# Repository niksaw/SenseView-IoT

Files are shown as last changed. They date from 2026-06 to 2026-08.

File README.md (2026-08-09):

# SenseView – Modular IoT Environmental Monitoring Platform

> **An end-to-end IoT platform engineered from concept to deployment, integrating custom hardware, embedded firmware, and a scalable edge-to-cloud data pipeline.**

<p align="center">
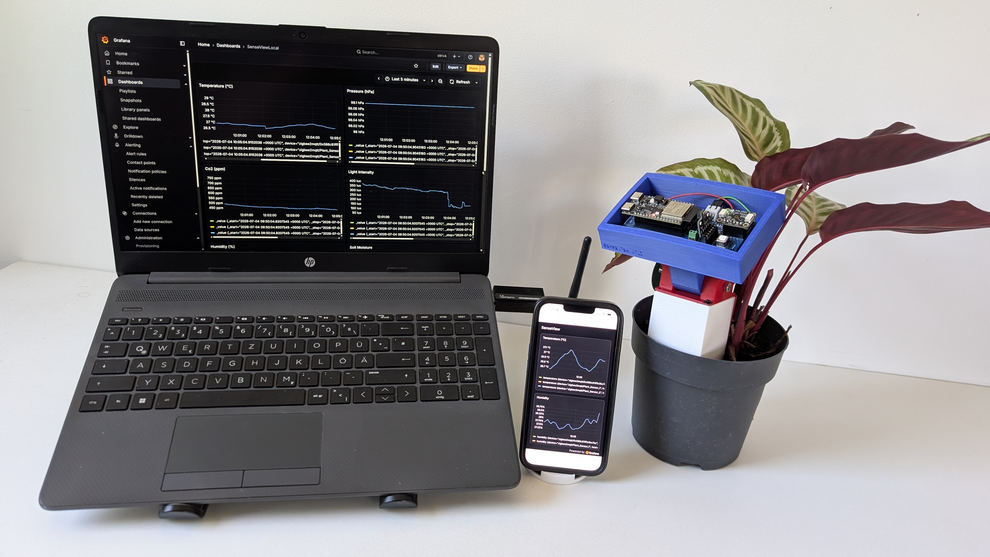
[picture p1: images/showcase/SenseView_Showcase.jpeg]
  
</p>
<p align="center">
  
  
  
  
</p>

## Overview

SenseView is a battery-powered IoT environmental monitoring platform developed to demonstrate the complete lifecycle of an embedded IoT system—from hardware design and firmware development to data acquisition, visualization, and cloud integration.

Originally developed as part of a Master's thesis in Electrical and Microsystems Engineering, the project was driven by research objectives emphasizing measurement quality, reliability, modularity, and low-power operation rather than minimizing hardware cost. Consequently, hardware and sensor selection were based on engineering requirements rather than cost optimization.

The platform combines a custom-designed ESP32-C6 sensor node, modular embedded firmware, and a complete MQTT-based backend capable of simultaneously storing data in both local and cloud time-series databases. Although the current implementation uses Zigbee communication, the architecture was intentionally designed to support future migration to Wi-Fi or Thread/Matter with minimal changes.

---

# System Architecture

<p align="center">
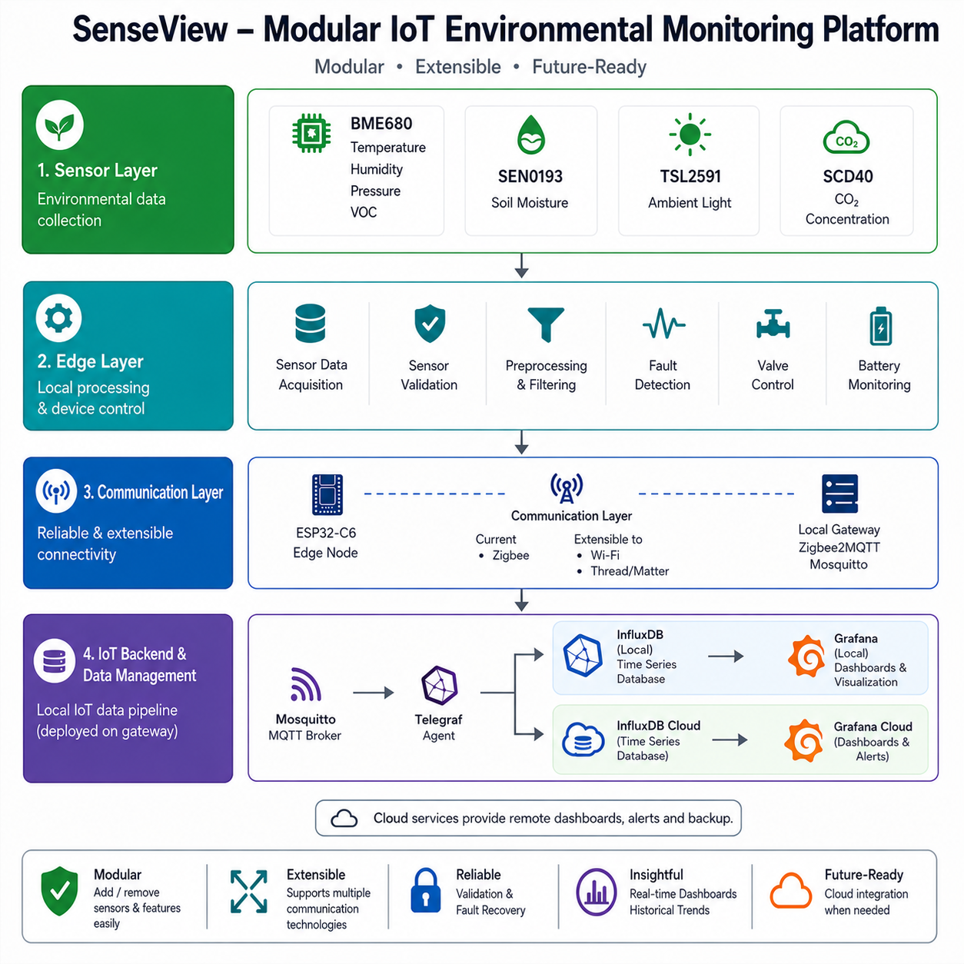
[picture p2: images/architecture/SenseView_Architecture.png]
  
</p>

---

# Engineering Highlights

- Designed and manufactured a custom ESP32-C6 PCB using KiCad.
- Developed embedded firmware for environmental sensing, sensor validation, preprocessing, fault detection, battery monitoring, and automated irrigation control.
- Built a complete MQTT-based IoT backend using Mosquitto, Telegraf, InfluxDB, and Grafana.
- Implemented simultaneous local and cloud data storage using Telegraf dual-output configuration.
- Designed the communication layer to remain extensible to Zigbee, Wi-Fi, and Thread/Matter.
- Designed a custom deployment enclosure using SolidWorks.
- Integrated environmental sensing, data visualization, and irrigation control into a single modular IoT platform.

---

# Technology Stack

| Category | Technology |
|---|---|
| Microcontroller | ESP32-C6 |
| Sensors | SCD40, BME680, TSL2591, SEN0193 |
| Communication | Zigbee (Extensible to Wi-Fi & Thread/Matter) |
| Firmware | Arduino Framework (C++) |
| MQTT Broker | Mosquitto |
| Data Collection | Telegraf |
| Database | InfluxDB + InfluxDB Cloud |
| Dashboard | Grafana + Grafana Cloud |
| PCB Design | KiCad |
| Mechanical Design | SolidWorks |

---

# Gallery

## Complete Device
Battery-powered prototype assembled inside the custom enclosure prior to deployment.
<p align="center">
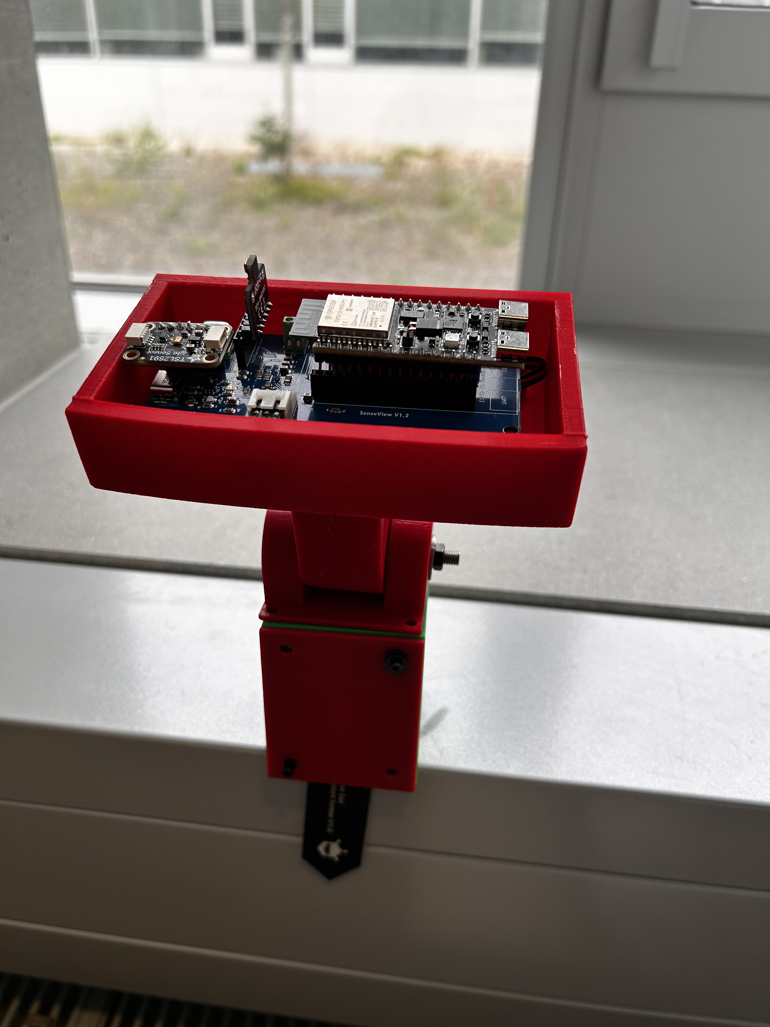
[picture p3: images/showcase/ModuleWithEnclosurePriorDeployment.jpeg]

</p>

## Custom PCB
PCB integrating the ESP32-C6, environmental sensors, battery management, and expansion headers.
<p align="center">
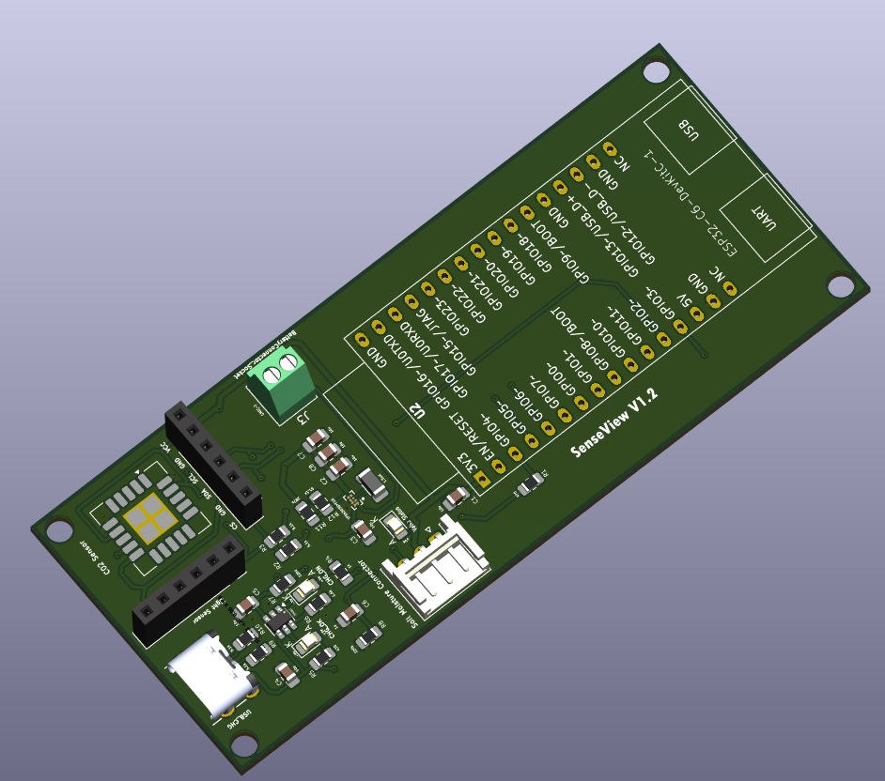
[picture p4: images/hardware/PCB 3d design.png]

</p>

## Grafana Dashboard
Real-time visualization of environmental data collected from the deployed sensor node
<p align="center">
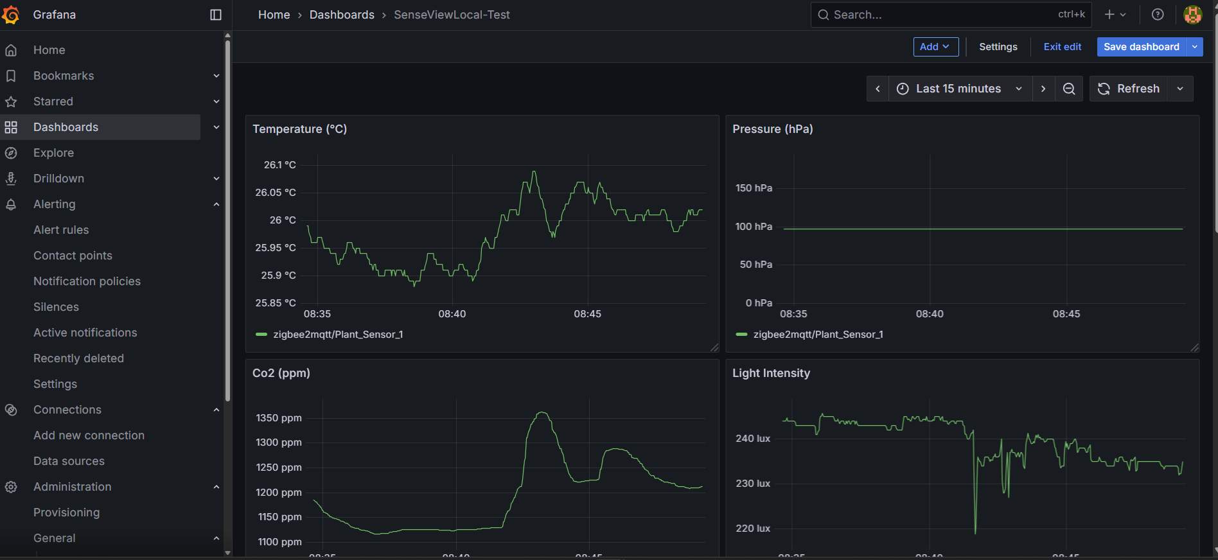
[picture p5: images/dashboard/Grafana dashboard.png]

</p>

## Deployment
Prototype deployed for indoor environmental monitoring
<p align="center">
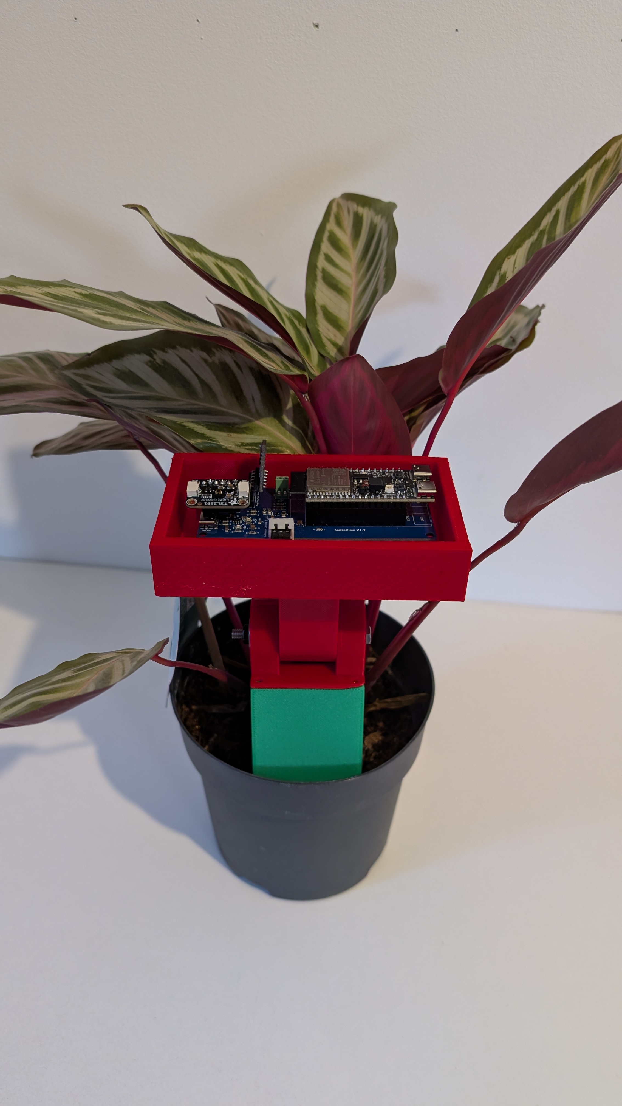
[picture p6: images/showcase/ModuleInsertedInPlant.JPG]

</p>

---

# Hardware

## Microcontroller

- ESP32-C6 Development Board

## Sensors

| Sensor | Purpose |
|---|---|
| Sensirion SCD40 | CO₂ Concentration |
| Bosch BME680 | Temperature, Humidity, Pressure, VOC |
| Adafruit TSL2591 | Ambient Light |
| DFRobot SEN0193 | Soil Moisture |

## Additional Hardware

- Custom PCB
- Li-Po Battery
- Solenoid Valve
- Custom 3D Printed Enclosure

---

# Software Architecture

## Embedded Firmware

- Sensor acquisition
- Sensor validation
- Data preprocessing
- Battery monitoring
- Irrigation control
- Fault detection

## Communication

- Zigbee
- Zigbee2MQTT

## Backend

- Mosquitto MQTT Broker
- Telegraf
- Local InfluxDB
- InfluxDB Cloud
- Local Grafana
- Grafana Cloud

---

# Repository Structure

```text
firmware/
    ESP32-C6 firmware

hardware/
    bom/
    gerbers/
    kicad/

enclosure/
    SolidWorks enclosure

images/
    architecture/
    dashboard/
    hardware/
    showcase/
```

---
# Engineering Decisions

| Decision | Reason |
|---|---|
| ESP32-C6 | Supports Zigbee, Wi-Fi and native Thread, enabling a modular communication architecture. |
| Zigbee | Low-power communication suitable for battery-operated IoT devices and readily available laboratory infrastructure. |
| BME680 | Higher measurement capability including VOC sensing compared to BME280. |
| Custom PCB | Improved robustness, compactness and deployment reliability compared to breadboard prototypes. |
| Telegraf | Flexible preprocessing and simultaneous transmission to both local and cloud InfluxDB instances. |

---

# Engineering Challenges

Some of the most significant engineering challenges encountered during this project included:

- Designing a reliable battery-powered power supply and custom PCB.
- Developing a complete IoT backend from MQTT through cloud visualization.
- Developing custom Zigbee2MQTT integration for seamless communication with the local IoT infrastructure.
- Designing a modular architecture capable of supporting future communication technologies with minimal hardware changes.

---

# Future Improvements

- Wi-Fi communication backend
- Native Thread / Matter implementation
- OTA firmware updates
- Further power optimization
- Configuration interface
- Mobile application

---

# Project Background

This project was developed as part of a Master's thesis in Electrical and Microsystems Engineering at OTH Regensburg.

Rather than focusing on building a single-purpose plant monitoring device, the objective was to engineer a reusable IoT platform capable of supporting environmental sensing applications while remaining modular, scalable and suitable for future communication technologies.

---

# Acknowledgements

I would like to thank my thesis supervisor and OTH Regensburg for providing the opportunity and research environment for this project.

---

# License

This project is licensed under the MIT License.

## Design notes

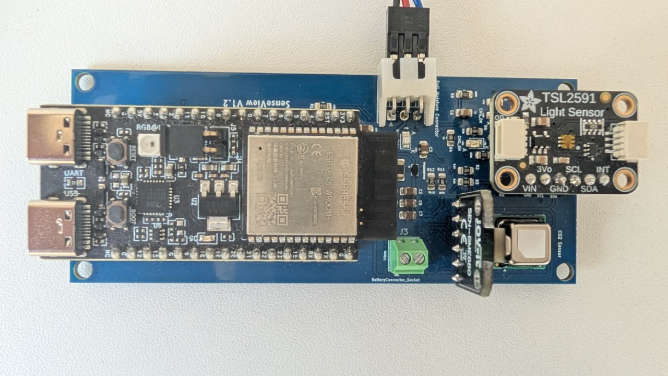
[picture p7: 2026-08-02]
images/hardware/TopView.png

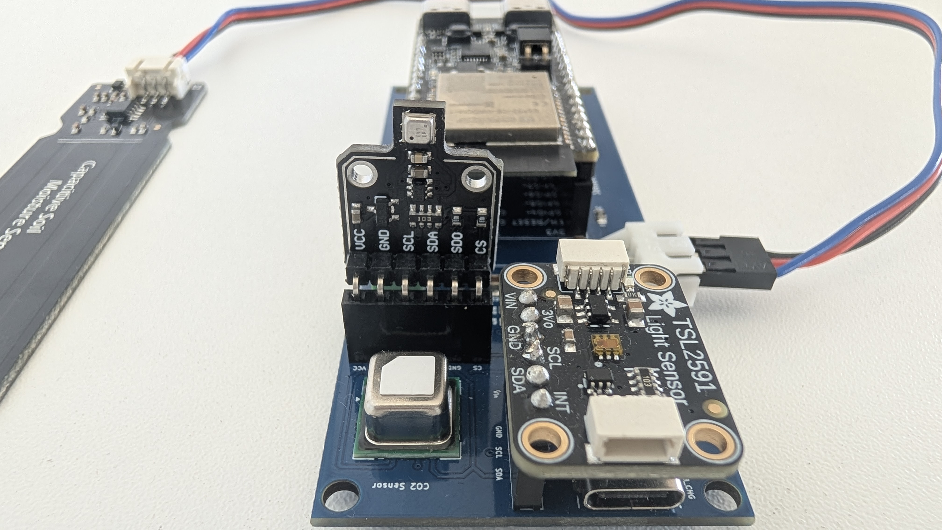
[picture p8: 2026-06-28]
images/hardware/SideView_3.jpeg

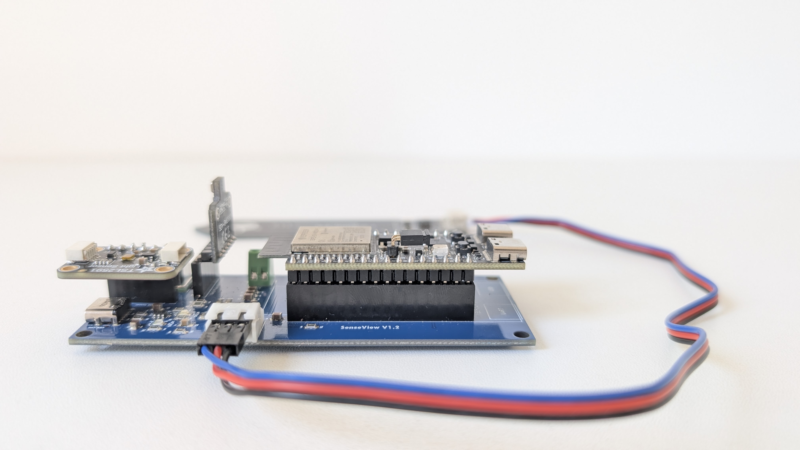
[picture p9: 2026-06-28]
images/hardware/SideView_1.jpeg

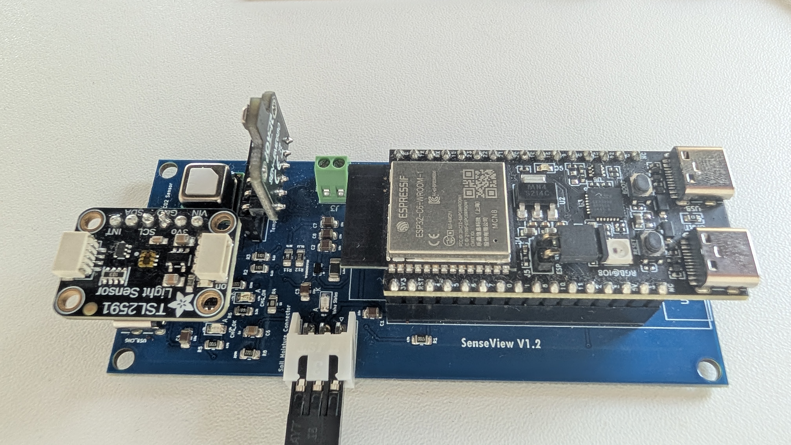
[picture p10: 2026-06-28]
images/hardware/SideView_2.jpeg

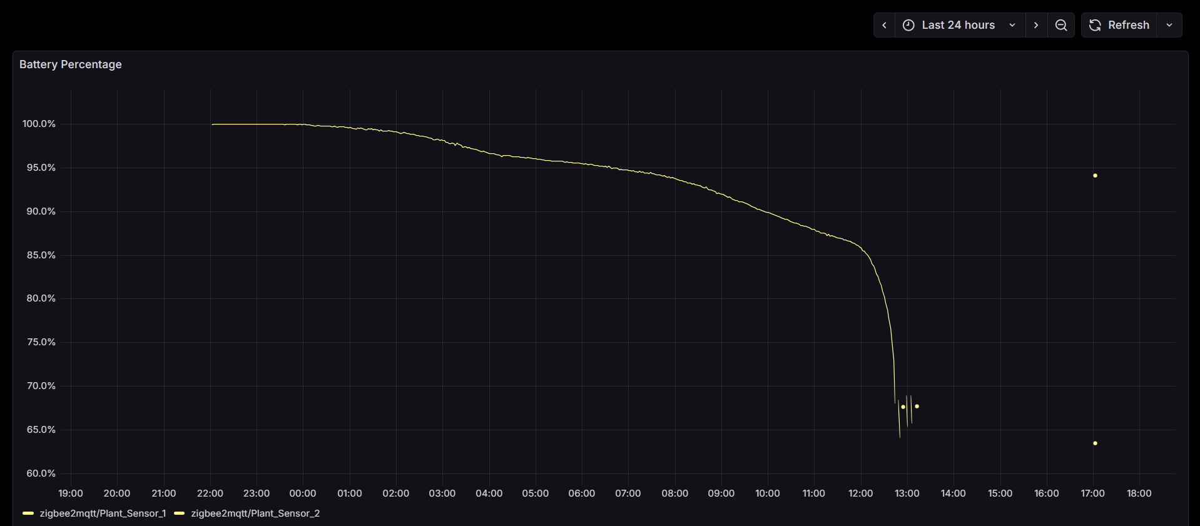
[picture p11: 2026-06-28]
images/dashboard/Battery SC.png

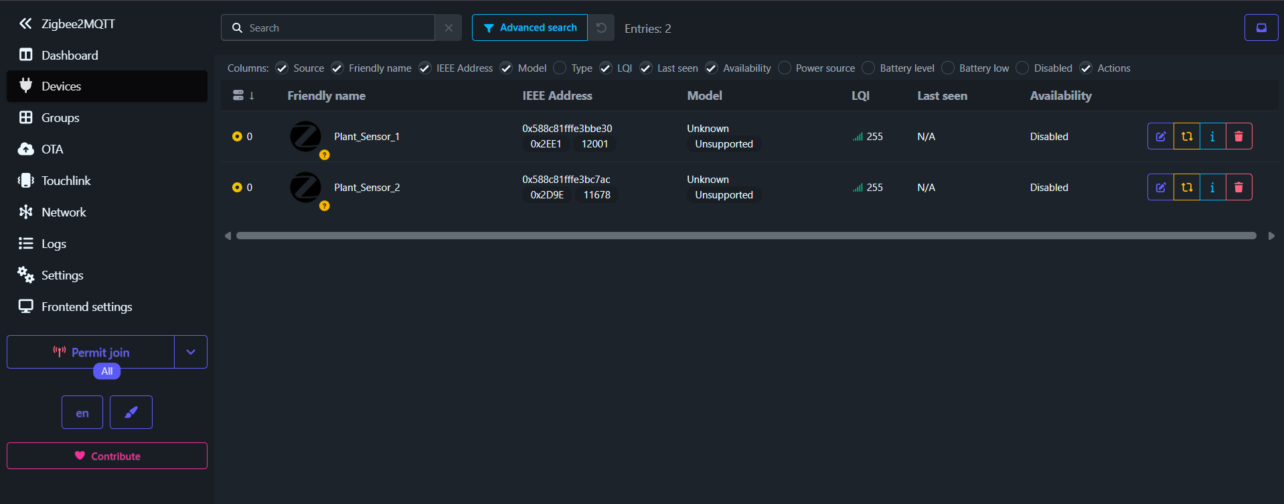
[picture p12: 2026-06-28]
images/dashboard/Zigbee2MQTTDashboad.png

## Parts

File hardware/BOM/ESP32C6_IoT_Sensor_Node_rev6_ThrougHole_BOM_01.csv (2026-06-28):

Reference | Qty | Value | DNP | Exclude from BOM | Exclude from Board | Footprint | Datasheet | JLCPCB Part #
C1,C2,C3,C4,C5,C7,C8 | 7 | 10u |  |  |  | Capacitor_SMD:C_0805_2012Metric_Pad1.18x1.45mm_HandSolder | ~ | C440198
C6 | 1 | 1u |  |  |  | Capacitor_SMD:C_0805_2012Metric_Pad1.18x1.45mm_HandSolder | ~ | C28323
D1 | 1 | Green LED |  |  |  | LED_SMD:LED_0805_2012Metric_Pad1.15x1.40mm_HandSolder | ~ | C2297
D2 | 1 | Valve LED Indicator |  |  |  | LED_SMD:LED_0805_2012Metric_Pad1.15x1.40mm_HandSolder | ~ | C434433
D3 | 1 | RED LED |  |  |  | LED_SMD:LED_0805_2012Metric_Pad1.15x1.40mm_HandSolder | ~ | C284871
J1 | 1 | SEN0193_Soil_Moisture Connector | DNP |  |  | Connector_JST:JST_EH_S3B-EH_1x03_P2.50mm_Horizontal | ~
J2 | 1 | 2171750001 |  |  |  | 217175-0001 USB Type C:MOLEX_2171750001 |  | C3197922
J3 | 1 | BatteryConnector_Socket |  |  |  | TerminalBlock_Phoenix:TerminalBlock_Phoenix_MPT-0,5-2-2.54_1x02_P2.54mm_Horizontal | ~ | C918120
L1 | 1 | 1.5uH |  |  |  | Inductor_SMD:L_1206_3216Metric | ~ | C2885920
R1,R5 | 2 | 470 |  |  |  | Resistor_SMD:R_0805_2012Metric_Pad1.20x1.40mm_HandSolder | ~ | C17710
R2,R3,R9,R10 | 4 | 5.1k |  |  |  | Resistor_SMD:R_0805_2012Metric_Pad1.20x1.40mm_HandSolder | ~ | C27834
R4 | 1 | 1k |  |  |  | Resistor_SMD:R_0805_2012Metric_Pad1.20x1.40mm_HandSolder | ~ | C17513
R6 | 1 | 1.6k |  |  |  | Resistor_SMD:R_0805_2012Metric_Pad1.20x1.40mm_HandSolder | ~ | C2933328
R7,R8 | 2 | 220k |  |  |  | Resistor_SMD:R_0805_2012Metric_Pad1.20x1.40mm_HandSolder | ~ | C17556
R11 | 1 | 287k |  |  |  | Resistor_SMD:R_0805_2012Metric_Pad1.20x1.40mm_HandSolder | ~ | C2933396
R12 | 1 | 51.1k |  |  |  | Resistor_SMD:R_0805_2012Metric_Pad1.20x1.40mm_HandSolder | ~ | C138264
U1 | 1 | BME680_THT | DNP |  |  | Connector_PinSocket_2.54mm:PinSocket_1x06_P2.54mm_Vertical | https://www.joy-it.net/files/files/Produkte/SEN-BME680/SEN-BME680_Manual_2024-04-11.pdf
U2 | 1 | ESP32-C6-DevKitC-1 | DNP |  |  | Espressif:ESP32-C6-DevKitC-1 | https://docs.espressif.com/projects/espressif-esp-dev-kits/en/latest/esp32c6/esp32-c6-devkitc-1/user_guide.html
U3 | 1 | SCD40-D-R2 |  |  |  | Sensor:Sensirion_SCD4x-1EP_10.1x10.1mm_P1.25mm_EP4.8x4.8mm | https://sensirion.com/media/documents/E0F04247/631EF271/CD_DS_SCD40_SCD41_Datasheet_D1.pdf | C3659421
U4 | 1 | TSL 2591_THT | DNP |  |  | Connector_PinSocket_2.54mm:PinSocket_1x06_P2.54mm_Vertical | https://ams.com/documents/20143/9331680/TSL2591_DS000338_7-00.pdf
U5 | 1 | TP4057 |  |  |  | Package_TO_SOT_SMD:TSOT-23-6 | http://toppwr.com/uploadfile/file/20230304/640302a47b738.pdf | C725791
U6 | 1 | TPS63036YFGR |  |  |  | TPS63036YFGR:BGA8N40P4X2_181X107X62N |  | C283955

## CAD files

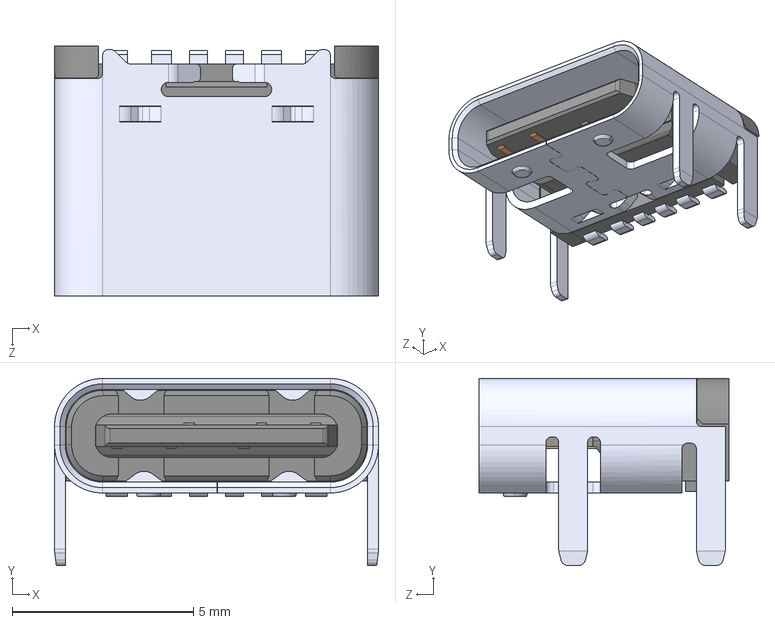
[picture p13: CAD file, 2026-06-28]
hardware/kicad/Footprint/2171750001.step
8.94 x 5.16 x 6.90 mm

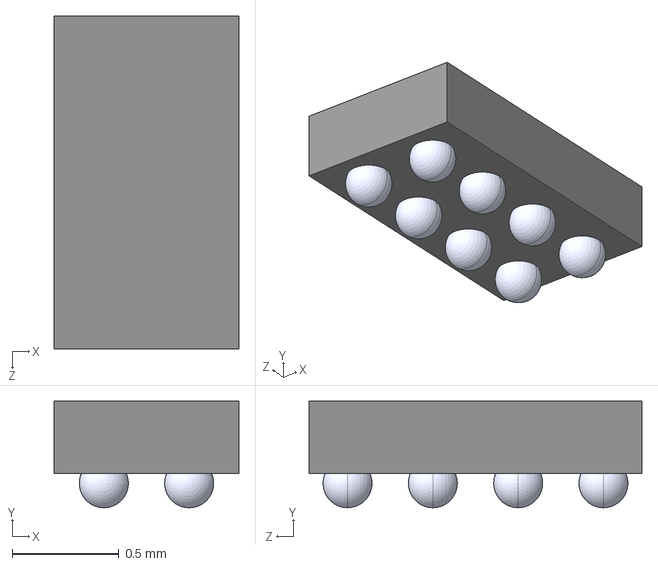
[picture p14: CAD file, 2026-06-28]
hardware/kicad/Footprint/TPS63036YFGR.step
0.866 x 0.5 x 1.56 mm

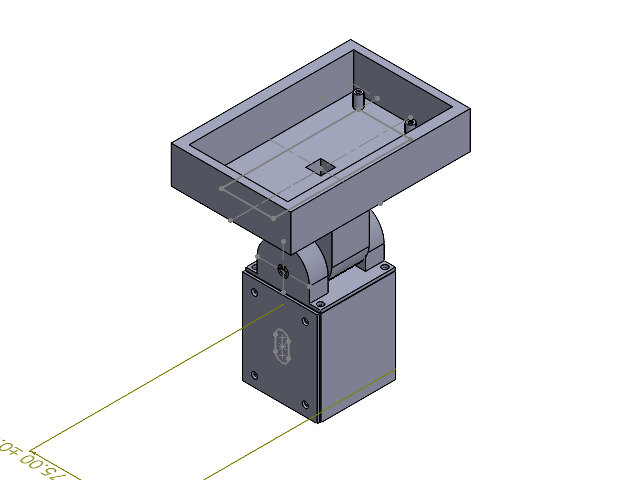
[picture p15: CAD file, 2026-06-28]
enclosure/SenseView_EnclosureV2.SLDASM
Enclosure_BottomSection1
Enclosure_MidSectionHinge1
Enclosure_MidSection
Enclosure_BottomSectionCover

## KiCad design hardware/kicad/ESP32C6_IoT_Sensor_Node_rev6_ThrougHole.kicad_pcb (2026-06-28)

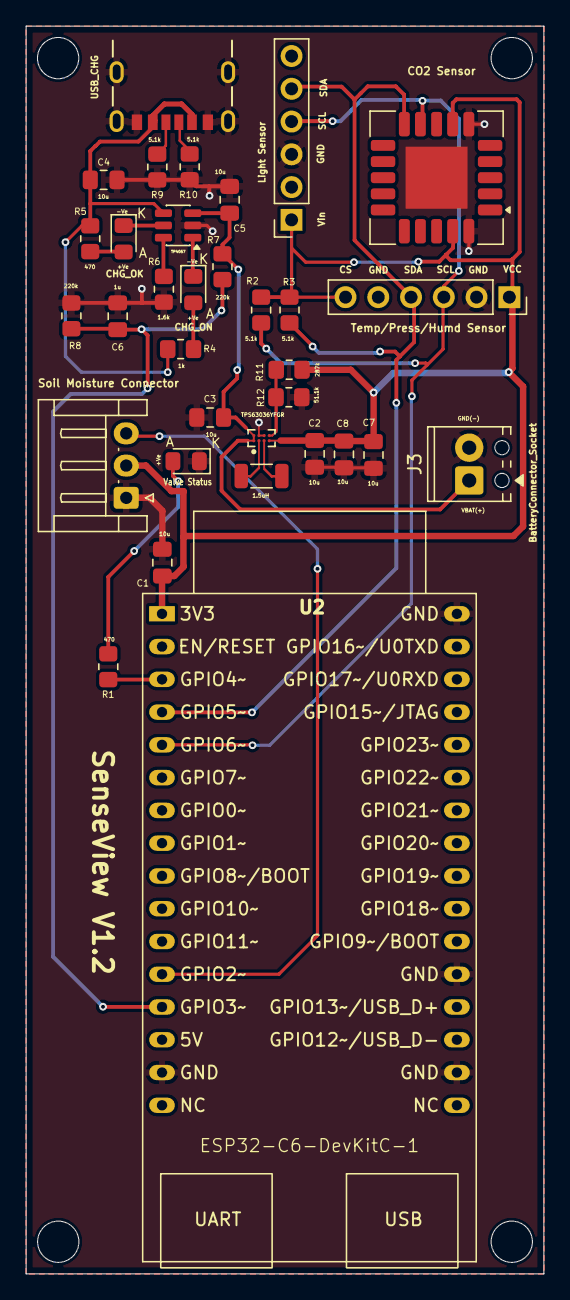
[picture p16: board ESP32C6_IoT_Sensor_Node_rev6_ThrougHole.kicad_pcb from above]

Board: 2 copper layers, 40.1 x 96.7 mm, 33 parts (0 on the bottom side), 20 nets.

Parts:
C1, C2, C3, C4, C5, C7, C8: 10u; C_0805_2012Metric_Pad1.18x1.45mm_HandSolder
C6: 1u; C_0805_2012Metric_Pad1.18x1.45mm_HandSolder
D1: CHG_OK; LED_0805_2012Metric_Pad1.15x1.40mm_HandSolder
D2: Valve Status; LED_0805_2012Metric_Pad1.15x1.40mm_HandSolder
D3: CHG_ON; LED_0805_2012Metric_Pad1.15x1.40mm_HandSolder
J1: Soil Moisture Connector; JST_EH_S3B-EH_1x03_P2.50mm_Horizontal
J2: USB_CHG; MOLEX_2171750001
J3: BatteryConnector_Socket; TerminalBlock_Phoenix_MPT-0,5-2-2.54_1x02_P2.54mm_Horizontal
L1: 1.5uH; L_1206_3216Metric
R1, R5: 470; R_0805_2012Metric_Pad1.20x1.40mm_HandSolder
R2, R3, R9, R10: 5.1k; R_0805_2012Metric_Pad1.20x1.40mm_HandSolder
R4: 1k; R_0805_2012Metric_Pad1.20x1.40mm_HandSolder
R6: 1.6k; R_0805_2012Metric_Pad1.20x1.40mm_HandSolder
R7, R8: 220k; R_0805_2012Metric_Pad1.20x1.40mm_HandSolder
R11: 287k; R_0805_2012Metric_Pad1.20x1.40mm_HandSolder
R12: 51.1k; R_0805_2012Metric_Pad1.20x1.40mm_HandSolder
U1: Temp/Press/Humd Sensor; PinSocket_1x06_P2.54mm_Vertical
U2: ESP32-C6-DevKitC-1
U3: CO2 Sensor; Sensirion_SCD4x-1EP_10.1x10.1mm_P1.25mm_EP4.8x4.8mm
U4: Light Sensor; PinSocket_1x06_P2.54mm_Vertical
U5: TP4057; TSOT-23-6
U6: TPS63036YFGR; BGA8N40P4X2_181X107X62N

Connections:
5V: C4.1, J2.A9 (VBUS1), J2.B9 (VBUS2), R4.1, R5.1, U5.4 (V_{CC})
+3.3V: C1.1, C2.1, C7.1, C8.1, J1.2, R2.2, R3.2, R11.2, U1.1 (VCC), U1.6 (CS), U2.1 (3V3), U3.7 (VDD), U3.19 (VDD), U4.1 (VIN), U6.D1 (VOUT)
ADC: C6.1, R7.2, R8.1, U2.13 (GPIO3)
GND: C1.2, C2.2, C3.2, C4.2, C5.2, C6.2, C7.2, C8.2, D2.1 (K), J1.1, J2.A12 (GND1), J2.B12 (GND2), J2.SH1 (SHIELD1), J2.SH2 (SHIELD2), J2.SH3 (SHIELD3), J2.SH4 (SHIELD4), J3.2, R6.1, R8.2, R9.1, R10.1, R12.1, U1.2 (GND), U2.15 (GND), U2.18 (GND), U2.21 (GND), U2.32 (GND), U3.6 (GND), U3.20 (GND), U3.21 (GND), U4.3 (GND), U5.2 (GND), U6.B2 (PS/SYNC), U6.C2 (GND)
I2C_SCL: R2.1, U1.3 (SCL), U2.5 (GPIO6), U3.9 (SCL), U4.4 (SCL)
I2C_SDA: R3.1, U1.4 (SDA), U2.4 (GPIO5/MTDI), U3.10 (SDA), U4.5 (SDA)
unnamed: D1.2 (A), R5.2
unnamed: D1.1 (K), U5.5 (STDBY)
unnamed: D2.2 (A), R1.1
unnamed: D3.2 (A), R4.2
unnamed: D3.1 (K), U5.1 (~CHRG)
unnamed: J2.A5 (CC1), R10.2
unnamed: J2.B5 (CC2), R9.2
unnamed: R1.2, U2.3 (GPIO4/MTMS)
unnamed: R6.2, U5.6 (PROG)
unnamed: R11.1, R12.2, U6.D2 (FB)
unnamed: L1.1, U6.B1 (L1)
unnamed: L1.2, U6.C1 (L2)
SMS: J1.3, U2.12 (GPIO2)
VBAT: C3.1, C5.1, J3.1, R7.1, U5.3 (BAT), U6.A1 (VIN), U6.A2 (EN)

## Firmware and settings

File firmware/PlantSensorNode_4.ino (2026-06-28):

#include <Wire.h>
#include <math.h>
#include <Adafruit_Sensor.h>
#include <Adafruit_BME680.h>
#include <Adafruit_TSL2591.h>
#include <SensirionI2cScd4x.h>
#include "Zigbee.h"

// =====================
// Pin Definitions
// =====================
#define SOIL_MOISTURE_PIN 2
#define BATTERY_ADC_PIN   3
#define I2C_SDA_PIN       5
#define I2C_SCL_PIN       6
#define LED_PIN           LED_BUILTIN
#define VALVE_GPIO_PIN    4

// =====================
// ADC / Battery
// =====================
#define ADC_MAX_VALUE     4095.0
#define ADC_REF_VOLT      3.3

// =====================
// Soil Calibration
// =====================
#define SOIL_AIR_VALUE    2300
#define SOIL_DRY_VALUE    2150
#define SOIL_WET_VALUE    1500

// =====================
// Valve Control
// =====================
#define LOW_THRESHOLD     30
#define HIGH_THRESHOLD    45
#define MAX_ON_TIME       (20UL * 60UL * 1000UL)

// =====================
// BME680 Sanity Limits
// =====================
#define BME_HUM_MAX       99.9f
#define BME_PRES_MIN      80000.0f
#define BME_GAS_MIN       1000.0f

// =====================
// BME680 Staleness Detection
// =====================
#define STALE_COUNT_MAX   15
#define STALE_DELTA       0.05f
#define BME_READ_INTERVAL 2000UL

// =====================
// State Variables
// =====================
bool valveState = false;
bool faultState = false;
bool bmeOK = false;
bool tslOK = false;
bool scdOK = false;

unsigned long valveOnStartTime = 0;

float lastTemp = -999.0f;
float lastHum  = -999.0f;
float lastPres = -999.0f;

uint8_t staleCount = 0;
unsigned long lastBmeRead = 0;

// =====================
// Sensors
// =====================
Adafruit_BME680   bme;
Adafruit_TSL2591  tsl = Adafruit_TSL2591(2591);
SensirionI2cScd4x scd4x;

// =====================
// Zigbee Endpoints
// =====================
ZigbeeLight               zbLED(1);
ZigbeeTempSensor          zbTempHum(2);
ZigbeePressureSensor      zbPres(3);
ZigbeeIlluminanceSensor   zbLux(4);
ZigbeeTempSensor          zbSoil(5);
ZigbeeCarbonDioxideSensor zbCO2(6);

// Custom battery endpoint only
ZigbeeAnalog              zbBattery(7);

tsl2591Gain_t tslGain = TSL2591_GAIN_MED;

// =====================
// LED Callback
// =====================
void setLED(bool state) {
  digitalWrite(LED_PIN, state);
}

// =====================
// TSL2591 Auto-range
// =====================
void tslAutoRange(uint16_t full) {

  if (full < 100 && tslGain != TSL2591_GAIN_MAX) {
    tslGain = (tsl2591Gain_t)(tslGain + 1);
    tsl.setGain(tslGain);
    delay(50);
  }

  if (full > 30000 && tslGain != TSL2591_GAIN_LOW) {
    tslGain = (tsl2591Gain_t)(tslGain - 1);
    tsl.setGain(tslGain);
    delay(50);
  }
}

// =====================
// BME680 Garbage Detector
// =====================
bool isGarbage() {

  if (bme.humidity >= BME_HUM_MAX)
    return true;

  if (bme.pressure < BME_PRES_MIN)
    return true;

  if (bme.gas_resistance < BME_GAS_MIN)
    return true;

  return false;
}

// =====================
// BME680 Staleness Detector
// =====================
bool isStale() {

  bool tempSame =
      fabsf(bme.temperature - lastTemp) < STALE_DELTA;

  bool humSame =
      fabsf(bme.humidity - lastHum) < STALE_DELTA;

  bool presSame =
      fabsf((bme.pressure / 100.0f) - lastPres) < STALE_DELTA;

  if (tempSame && humSame && presSame) {

    staleCount++;

  } else {

    staleCount = 0;

    lastTemp = bme.temperature;
    lastHum  = bme.humidity;
    lastPres = bme.pressure / 100.0f;
  }

  return (staleCount >= STALE_COUNT_MAX);
}

// =====================
// BME680 Init / Recovery
// =====================
bool initBME() {

  staleCount  = 0;
  lastTemp    = -999.0f;
  lastHum     = -999.0f;
  lastPres    = -999.0f;
  lastBmeRead = 0;

  Wire.begin(I2C_SDA_PIN, I2C_SCL_PIN);
  delay(100);

  if (!(bme.begin(0x76) || bme.begin(0x77))) {
    return false;
  }

  bme.setTemperatureOversampling(BME680_OS_4X);
  bme.setHumidityOversampling(BME680_OS_2X);
  bme.setPressureOversampling(BME680_OS_4X);
  bme.setIIRFilterSize(BME680_FILTER_SIZE_3);
  bme.setGasHeater(250, 100);

  return true;
}

// =====================
// Setup
// =====================
void setup() {

  pinMode(LED_PIN, OUTPUT);
  digitalWrite(LED_PIN, LOW);

  pinMode(VALVE_GPIO_PIN, OUTPUT);
  digitalWrite(VALVE_GPIO_PIN, LOW);

  pinMode(SOIL_MOISTURE_PIN, INPUT);
  pinMode(BATTERY_ADC_PIN, INPUT);

  // =====================
  // Zigbee Endpoints
  // =====================
  zbLED.onLightChange(setLED);
  Zigbee.addEndpoint(&zbLED);

  // Temperature + Humidity
  zbTempHum.addHumiditySensor(0, 100, 1);

  Zigbee.addEndpoint(&zbTempHum);

  // Pressure
  Zigbee.addEndpoint(&zbPres);

  // Lux
  Zigbee.addEndpoint(&zbLux);

  // Soil Moisture
  zbSoil.addHumiditySensor(0, 100, 1);
  Zigbee.addEndpoint(&zbSoil);

  // CO2
  Zigbee.addEndpoint(&zbCO2);

  // Battery endpoint
  zbBattery.addAnalogInput();
  Zigbee.addEndpoint(&zbBattery);

  Zigbee.setPrimaryChannelMask(0x00100000);

  // =====================
  // Start Zigbee
  // =====================
  if (!Zigbee.begin(ZIGBEE_END_DEVICE)) {
    while (1);
  }

  while (!Zigbee.connected()) {
    delay(300);
  }

  // =====================
  // Init Sensors
  // =====================
  Wire.begin(I2C_SDA_PIN, I2C_SCL_PIN);
  delay(100);

  // ---------- BME680 ----------
  bmeOK = initBME();

  // ---------- TSL2591 ----------
  if (tsl.begin()) {

    tsl.setGain(tslGain);
    tsl.setTiming(TSL2591_INTEGRATIONTIME_200MS);

    delay(300);

    tslOK = true;

    // Force Lux entity creation
    zbLux.setIlluminance(0);
    zbLux.report();
  }

  // ---------- SCD4x ----------
  scd4x.begin(Wire, 0x62);

  scd4x.stopPeriodicMeasurement();

  delay(500);

  if (scd4x.startPeriodicMeasurement() == 0) {
    scdOK = true;
  }
}

// =====================
// Main Loop
// =====================
void loop() {

  delay(10);

  // =====================
  // BME680
  // =====================
  if (bmeOK) {

    unsigned long now = millis();

    if (now - lastBmeRead >= BME_READ_INTERVAL) {

      lastBmeRead = now;

      if (!bme.performReading() ||
          isGarbage() ||
          isStale()) {

        bmeOK = initBME();

      } else {

        // Temperature + Humidity
        zbTempHum.setTemperature(bme.temperature);
        zbTempHum.setHumidity(bme.humidity);
        zbTempHum.report();

        // Pressure in hPa
        zbPres.setPressure(bme.pressure / 100.0f);
        zbPres.report();
      }
    }

  } else {

    static unsigned long lastRetry = 0;

    unsigned long now = millis();

    if (now - lastRetry >= 5000UL) {

      lastRetry = now;

      bmeOK = initBME();
    }
  }

  // =====================
  // Soil Moisture
  // =====================
  uint16_t soilRaw =
      analogRead(SOIL_MOISTURE_PIN);

  float soilPercent;

  if (soilRaw >= SOIL_AIR_VALUE) {

    soilPercent = 0.0f;

  } else {

    soilPercent =
        map(
            soilRaw,
            SOIL_DRY_VALUE,
            SOIL_WET_VALUE,
            0,
            100);

    soilPercent =
        constrain(soilPercent, 0, 100);
  }

  // Dummy temperature to avoid NaN
  zbSoil.setTemperature(0);

  // Soil moisture as humidity
  zbSoil.setHumidity(soilPercent);

  zbSoil.report();

  // =====================
  // TSL2591 Lux
  // =====================
  if (tslOK) {

    uint32_t lum =
        tsl.getFullLuminosity();

    uint16_t ir =
        lum >> 16;

    uint16_t full =
        lum & 0xFFFF;

    tslAutoRange(full);

    float lux =
        tsl.calculateLux(full, ir);

    if (isnan(lux) || lux < 0) {
      lux = 0;
    }

    // Convert lux to Zigbee illuminance format
    uint16_t zigbeeLux;

    if (lux <= 0.1f) {
      zigbeeLux = 0;
    } else {
      zigbeeLux =
          (uint16_t)(10000.0f * log10f(lux) + 1);
    }

    zbLux.setIlluminance(zigbeeLux);
    zbLux.report();
  }

// =====================
// Battery
// =====================
uint16_t adcRaw =
    analogRead(BATTERY_ADC_PIN);

// Calibrated voltage calculation
float battVoltage =
    ((float)adcRaw / ADC_MAX_VALUE) *
    ADC_REF_VOLT *
    1.262f *   // ADC calibration factor
    2.0f;      // 100k/100k divider

// Linear Li-ion estimation
float battPercent =
    (battVoltage - 3.0f) /
    (4.2f - 3.0f) *
    100.0f;

battPercent =
    constrain(
        battPercent,
        0.0f,
        100.0f);

zbBattery.setAnalogInput(battPercent);
zbBattery.reportAnalogInput();

  // =====================
  // CO2
  // =====================
  if (scdOK) {

    bool dataReady = false;

    scd4x.getDataReadyStatus(dataReady);

    if (dataReady) {

      uint16_t co2Raw = 0;
      float scdTemp   = 0.0f;
      float scdHum    = 0.0f;

      if (scd4x.readMeasurement(
              co2Raw,
              scdTemp,
              scdHum) == 0 &&
          co2Raw != 0) {

        zbCO2.setCarbonDioxide((float)co2Raw);
        zbCO2.report();
      }
    }
  }

  // =====================
  // Valve Logic
  // =====================
  if (!faultState) {

    if (!valveState &&
        soilPercent < LOW_THRESHOLD) {

      valveState = true;

      valveOnStartTime = millis();

      digitalWrite(VALVE_GPIO_PIN, HIGH);
    }

    else if (valveState &&
             soilPercent > HIGH_THRESHOLD) {

      valveState = false;

      digitalWrite(VALVE_GPIO_PIN, LOW);
    }

    if (valveState &&
        (millis() - valveOnStartTime >
         MAX_ON_TIME)) {

      valveState = false;
      faultState = true;

      digitalWrite(VALVE_GPIO_PIN, LOW);
    }
  }

  delay(1000);
}

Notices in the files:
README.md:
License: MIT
